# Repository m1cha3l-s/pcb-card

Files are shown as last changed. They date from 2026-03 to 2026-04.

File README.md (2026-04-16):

# m1cha3l's PCB Business card V1
You were luck enough to recieve my pcb business card! You can keep it in your wallet and use the built in ruler or solder the needed components and get a nice desk accessories which has a 6x6 NeoPixel MATRIX, 2 buttons, vibration motor for notifications and a BME280 sensor for presure, humidity and temerature and supports Zigbee, Matter, Thread and bluetooth and wifi.

## Building
You can buy the components I have in my bom to build this together! Also I included headers which you can solder to add more sensors for smart home!

## Firmware
I have included a simple firmware which shows red when the temp from BME280 is over 20℃ and green when under when you press button number 2 and vibrates and shows blue when you press button number 1.
1. Open Arduino IDE
2. Choose seeed xiao ESP32-C6
3. Flash and enjoy!!

## Looks

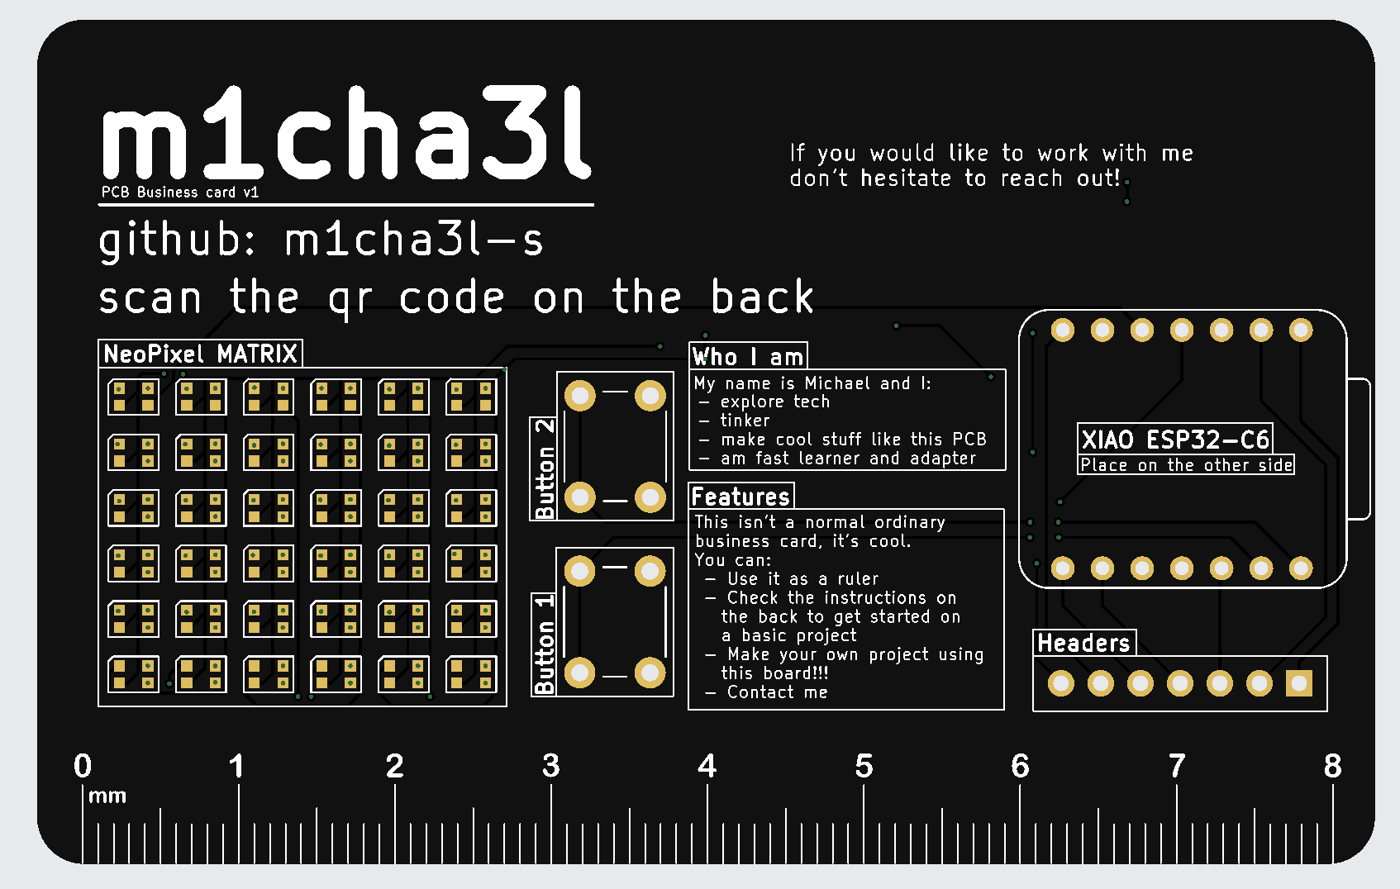
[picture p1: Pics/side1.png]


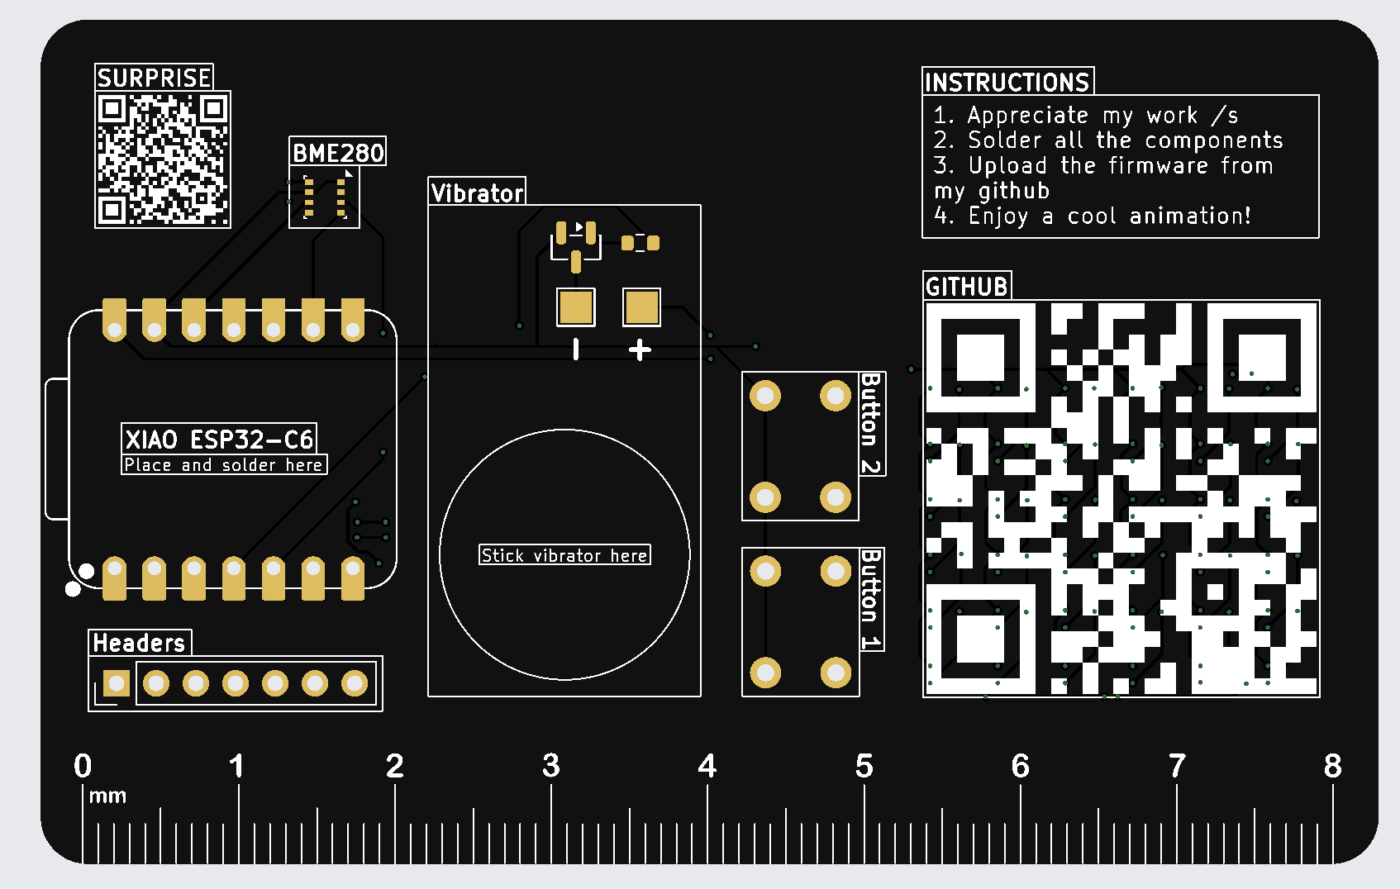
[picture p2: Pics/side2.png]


## Schematic and PCB
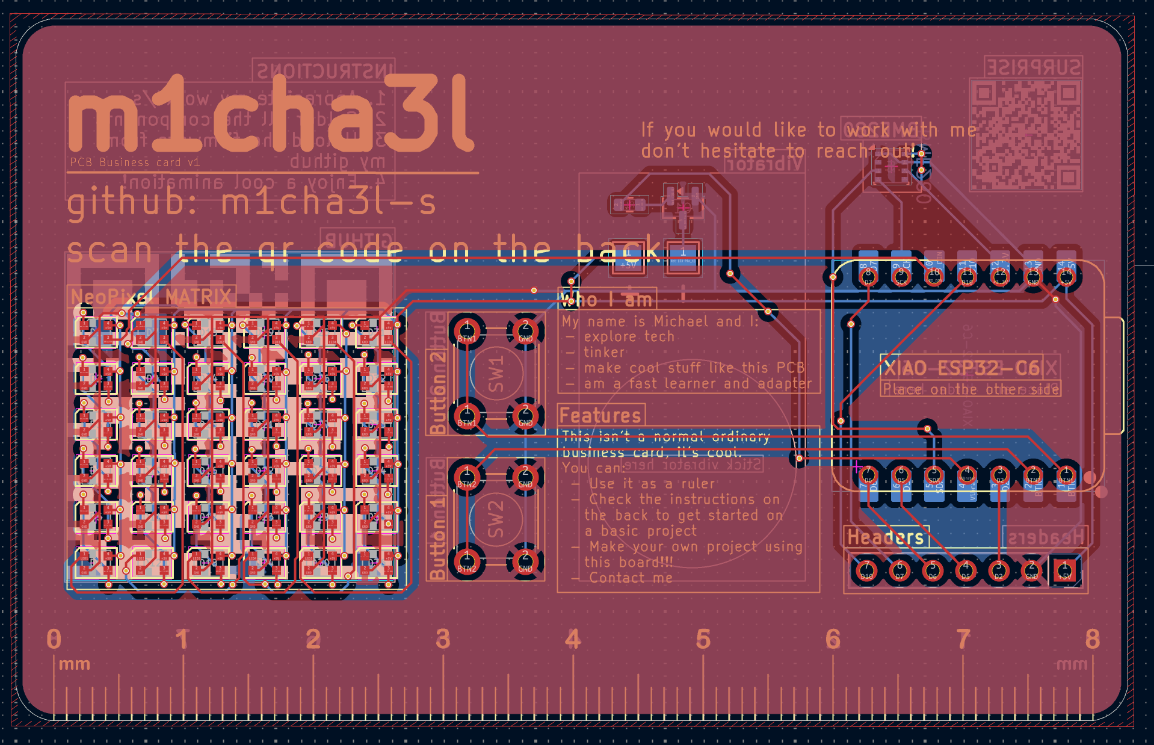
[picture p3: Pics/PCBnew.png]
PCB


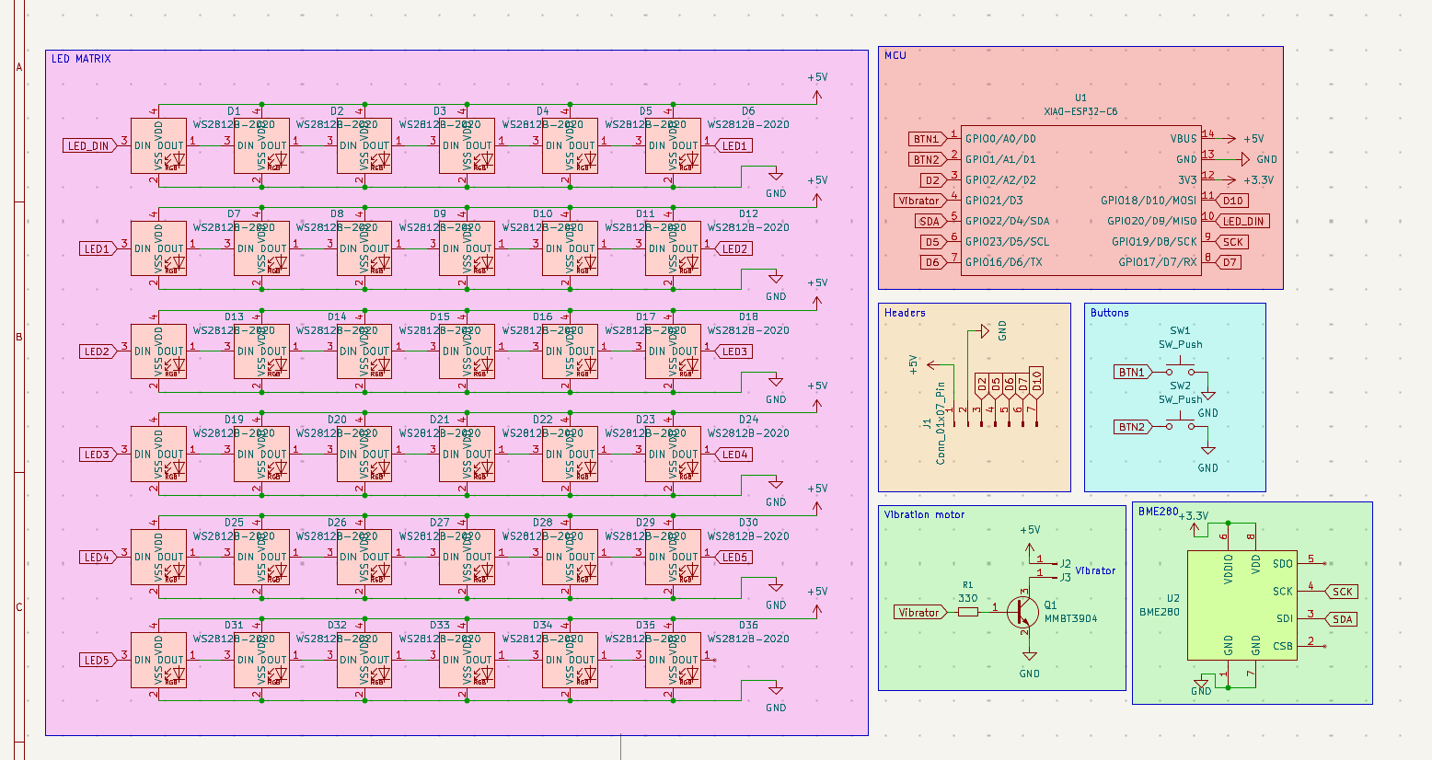
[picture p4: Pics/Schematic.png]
Schematic


## [BOM](https://github.com/m1cha3l-s/pcb-card/blob/main/BOM.csv)

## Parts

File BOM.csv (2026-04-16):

Name | Purpose | Quantity | Total Cost (USD) | Link | Distributor
PCB+Stencil+Shipping+Tax | PCB+Stencil cause idk how to without+Shipping global standart line which is cheapest(I have a 20$ coupon on JLCPCB which I would use to it comes out cheaper | 1 | 4.06 |  | jlcpcb
100PCS SOT-23 MMBT3904 | MMBT3904 | 1 | 0.42 | https://www.aliexpress.com/item/1005009793088130.html | Aliexpress
100PCS/LOTE 0603 SMD Resistor 0R-10M 1/8W 0 1 10 100 150 220 330 ohm 1K 2.2K 10K 100K 0R 1R 10R 100R 150R 220R 330R | SMD resistor | 1 | 0.53 | https://www.aliexpress.com/item/1005002068920572.html | Aliexpress
217℃ Lead-Free High Temp Solder Paste Sn96.5Ag3.0Cu0.5 Needle Tube | Solder paste to do the smd soldering | 1 | 3.21 | https://www.aliexpress.com/item/1005011848494455.html | Aliexpress
G3061 PD65W Mini Hot Plate Digital Soldering Preheating Rework Station PCB SMD Board Soldering Plate Heating Table Repair Tools | Tool to do SMD at home which is cheaper for this board than PCBA | 1 | 17.21 | https://www.aliexpress.com/item/1005006380068665.html | Aliexpress
20PCS Tact Push Button Switch 12V Copper 4Pin SMD Micro Switch 6X6X5 4.3 5 5.5 6 7 8 9 10 11 12 13 15MM TV Toys Home Use Button | Buttonsss (I have them already) | 1 | 0.00 | https://www.aliexpress.com/item/1005005834458965.html | Aliexpress
BME280 LGA-8 MEMS Digital Gas/Pressure/Temperature and Humidity Sensor IC Chip New Original | humidity, pressure and temperature sensor | 1 | 4.38 | https://www.aliexpress.com/item/1005006988103578.html | Aliexpress
50PCS WS2812B-2020 | LEDs for the NeoPixel MATRIX | 1 | 1.27 | https://www.aliexpress.com/item/1005008784230562.html | Aliexpress
DC 3V 3.7V 8mm Round Thin Vibration Motor Button Coin Vibrating Motor Vibrator Phone Massage | Vibration for the board | 1 | 0.41 | https://www.aliexpress.com/item/1005006821274949.html | Aliexpress
XIAO ESP32-C6 | the brain of the thing | 1 | 7.80 | https://botland.cz/moduly-wifi-a-bt-esp32/24783-seeed-xiao-esp32-c6-wifi-bluetooth-seeedstudio-113991254-5904422385705.html | botland

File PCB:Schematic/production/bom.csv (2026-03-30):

Designator | Footprint | Quantity | Value | LCSC Part #
 | f06da421-139f-4461-bd72-0d63481e1e29 | 1
D1, D10, D11, D12, D13, D14, D15, D16, D17, D18, D19, D2, D20, D21, D22, D23, D24, D25, D26, D27, D28, D29, D3, D30, D31, D32, D33, D34, D35, D36, D4, D5, D6, D7, D8, D9 | LED_WS2812B-2020_PLCC4_2.0x2.0mm | 36 | WS2812B-2020
J1 | PinHeader_1x07_P2.54mm_Vertical | 1 | Conn_01x07_Pin
J2, J3 | TestPoint_Pad_2.0x2.0mm | 2 | Conn_01x01_Pin
Q1 | SOT-23 | 1 | MMBT3904
R1 | 0603 | 1 | 330
SW1, SW2 | SW_PUSH_6mm_H4.3mm | 2 | SW_Push
U1 | XIAO-ESP32C6-DIP | 1 | XIAO-ESP32-C6
U2 | Bosch_LGA-8_2.5x2.5mm_P0.65mm_ClockwisePinNumbering | 1 | BME280

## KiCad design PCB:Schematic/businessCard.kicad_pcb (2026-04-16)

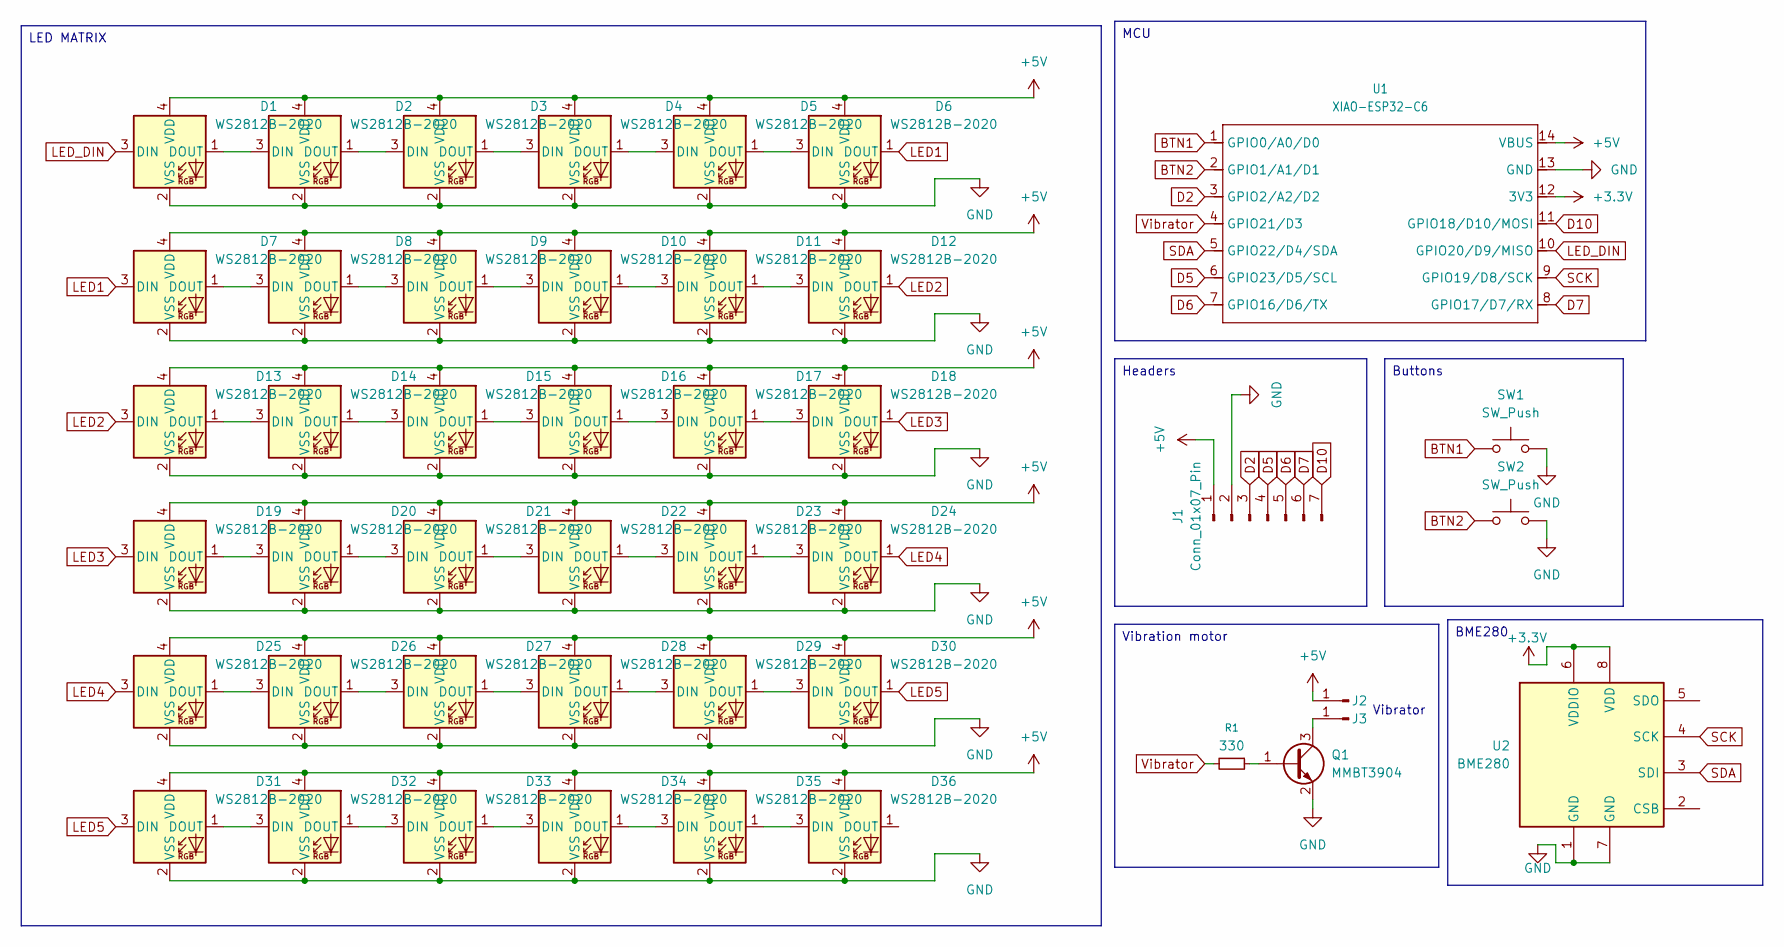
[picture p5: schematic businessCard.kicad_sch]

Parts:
D1, D2, D3, D4, D5, D6, D7, D8, D9, D10, D11, D12, D13, D14, D15, D16, D17, D18, D19, D20, D21, D22, D23, D24, D25, D26, D27, D28, D29, D30, D31, D32, D33, D34, D35, D36: WS2812B-2020; LED_WS2812B-2020_PLCC4_2.0x2.0mm
J1: Conn_01x07_Pin; PinHeader_1x07_P2.54mm_Vertical
J2, J3: Conn_01x01_Pin; TestPoint_Pad_2.0x2.0mm
Q1: MMBT3904; SOT-23
R1: 330; R_0603_1608Metric
SW1, SW2: SW_Push; SW_PUSH_6mm_H4.3mm
U1: XIAO-ESP32-C6; XIAO-ESP32C6-DIP
U2: BME280; Bosch_LGA-8_2.5x2.5mm_P0.65mm_ClockwisePinNumbering

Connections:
+3.3V: U1.12 (3V3), U2.6 (VDDIO), U2.8 (VDD)
+5V: D1.4 (VDD), D2.4 (VDD), D3.4 (VDD), D4.4 (VDD), D5.4 (VDD), D6.4 (VDD), D7.4 (VDD), D8.4 (VDD), D9.4 (VDD), D10.4 (VDD), D11.4 (VDD), D12.4 (VDD), D13.4 (VDD), D14.4 (VDD), D15.4 (VDD), D16.4 (VDD), D17.4 (VDD), D18.4 (VDD), D19.4 (VDD), D20.4 (VDD), D21.4 (VDD), D22.4 (VDD), D23.4 (VDD), D24.4 (VDD), D25.4 (VDD), D26.4 (VDD), D27.4 (VDD), D28.4 (VDD), D29.4 (VDD), D30.4 (VDD), D31.4 (VDD), D32.4 (VDD), D33.4 (VDD), D34.4 (VDD), D35.4 (VDD), D36.4 (VDD), J1.1, J2.1, U1.14 (VBUS)
BTN1: SW1.1, U1.1 (GPIO0/A0/D0)
BTN2: SW2.1, U1.2 (GPIO1/A1/D1)
D2: J1.3, U1.3 (GPIO2/A2/D2)
D5: J1.4, U1.6 (GPIO23/D5/SCL)
D6: J1.5, U1.7 (GPIO16/D6/TX)
D7: J1.6, U1.8 (GPIO17/D7/RX)
D10: J1.7, U1.11 (GPIO18/D10/MOSI)
GND: D1.2 (VSS), D2.2 (VSS), D3.2 (VSS), D4.2 (VSS), D5.2 (VSS), D6.2 (VSS), D7.2 (VSS), D8.2 (VSS), D9.2 (VSS), D10.2 (VSS), D11.2 (VSS), D12.2 (VSS), D13.2 (VSS), D14.2 (VSS), D15.2 (VSS), D16.2 (VSS), D17.2 (VSS), D18.2 (VSS), D19.2 (VSS), D20.2 (VSS), D21.2 (VSS), D22.2 (VSS), D23.2 (VSS), D24.2 (VSS), D25.2 (VSS), D26.2 (VSS), D27.2 (VSS), D28.2 (VSS), D29.2 (VSS), D30.2 (VSS), D31.2 (VSS), D32.2 (VSS), D33.2 (VSS), D34.2 (VSS), D35.2 (VSS), D36.2 (VSS), J1.2, Q1.2 (E), SW1.2, SW2.2, U1.13 (GND), U2.1 (GND), U2.7 (GND)
LED1: D6.1 (DOUT), D7.3 (DIN)
LED2: D12.1 (DOUT), D13.3 (DIN)
LED3: D18.1 (DOUT), D19.3 (DIN)
LED4: D24.1 (DOUT), D25.3 (DIN)
LED5: D30.1 (DOUT), D31.3 (DIN)
LED_DIN: D1.3 (DIN), U1.10 (GPIO20/D9/MISO)
unnamed: D1.1 (DOUT), D2.3 (DIN)
unnamed: D2.1 (DOUT), D3.3 (DIN)
unnamed: D3.1 (DOUT), D4.3 (DIN)
unnamed: D4.1 (DOUT), D5.3 (DIN)
unnamed: D5.1 (DOUT), D6.3 (DIN)
unnamed: D7.1 (DOUT), D8.3 (DIN)
unnamed: D8.1 (DOUT), D9.3 (DIN)
unnamed: D9.1 (DOUT), D10.3 (DIN)
unnamed: D10.1 (DOUT), D11.3 (DIN)
unnamed: D11.1 (DOUT), D12.3 (DIN)
unnamed: D13.1 (DOUT), D14.3 (DIN)
unnamed: D14.1 (DOUT), D15.3 (DIN)
unnamed: D15.1 (DOUT), D16.3 (DIN)
unnamed: D16.1 (DOUT), D17.3 (DIN)
unnamed: D17.1 (DOUT), D18.3 (DIN)
unnamed: D19.1 (DOUT), D20.3 (DIN)
unnamed: D20.1 (DOUT), D21.3 (DIN)
unnamed: D21.1 (DOUT), D22.3 (DIN)
unnamed: D22.1 (DOUT), D23.3 (DIN)
unnamed: D23.1 (DOUT), D24.3 (DIN)
unnamed: D25.1 (DOUT), D26.3 (DIN)
unnamed: D26.1 (DOUT), D27.3 (DIN)
unnamed: D27.1 (DOUT), D28.3 (DIN)
unnamed: D28.1 (DOUT), D29.3 (DIN)
unnamed: D29.1 (DOUT), D30.3 (DIN)
unnamed: D31.1 (DOUT), D32.3 (DIN)
unnamed: D32.1 (DOUT), D33.3 (DIN)
unnamed: D33.1 (DOUT), D34.3 (DIN)
unnamed: D34.1 (DOUT), D35.3 (DIN)
unnamed: D35.1 (DOUT), D36.3 (DIN)
unnamed: J3.1, Q1.3 (C)
unnamed: Q1.1 (B), R1.1
SCK: U1.9 (GPIO19/D8/SCK), U2.4 (SCK)
SDA: U1.5 (GPIO22/D4/SDA), U2.3 (SDI)
Vibrator: R1.2, U1.4 (GPIO21/D3)

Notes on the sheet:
Vibrator
Headers
LED MATRIX
MCU
BME280
Buttons
Vibration motor

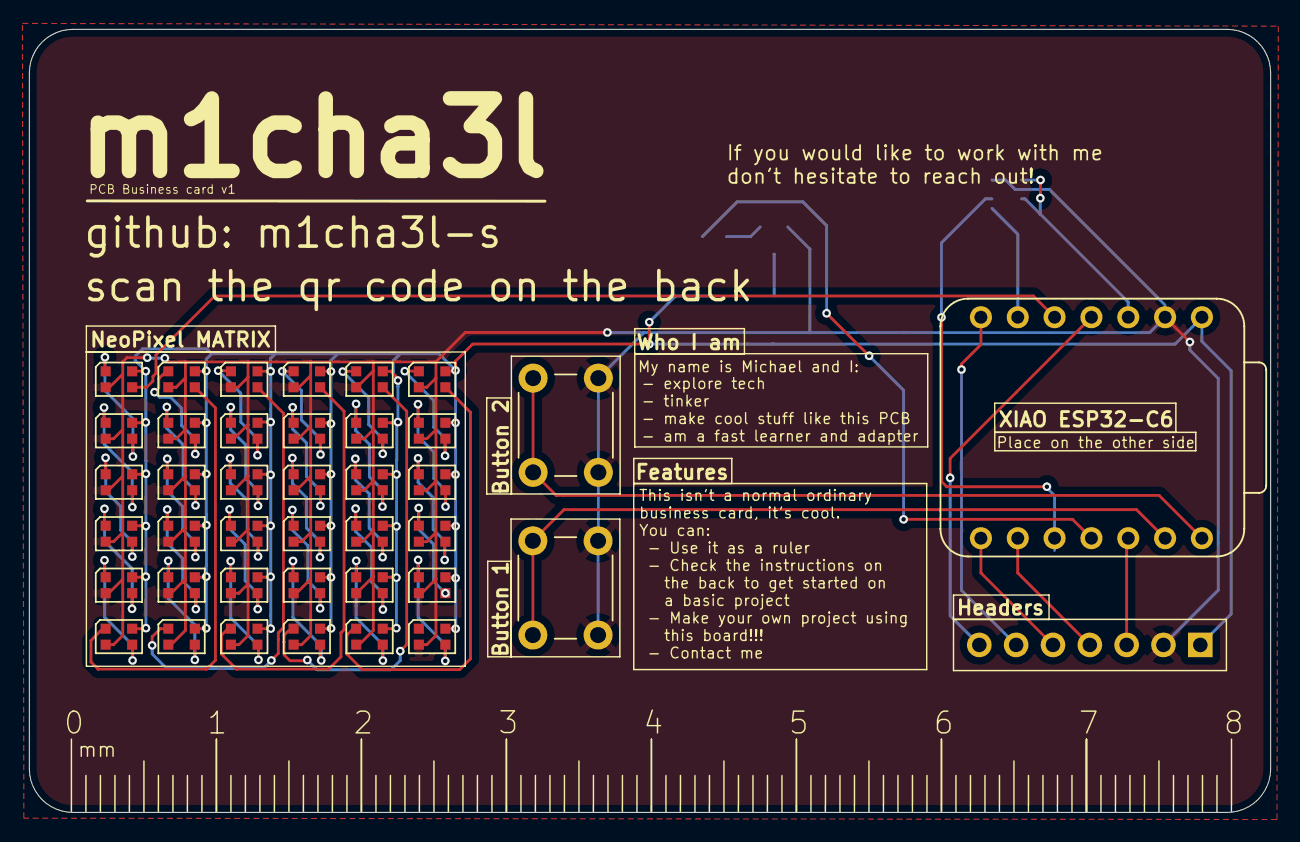
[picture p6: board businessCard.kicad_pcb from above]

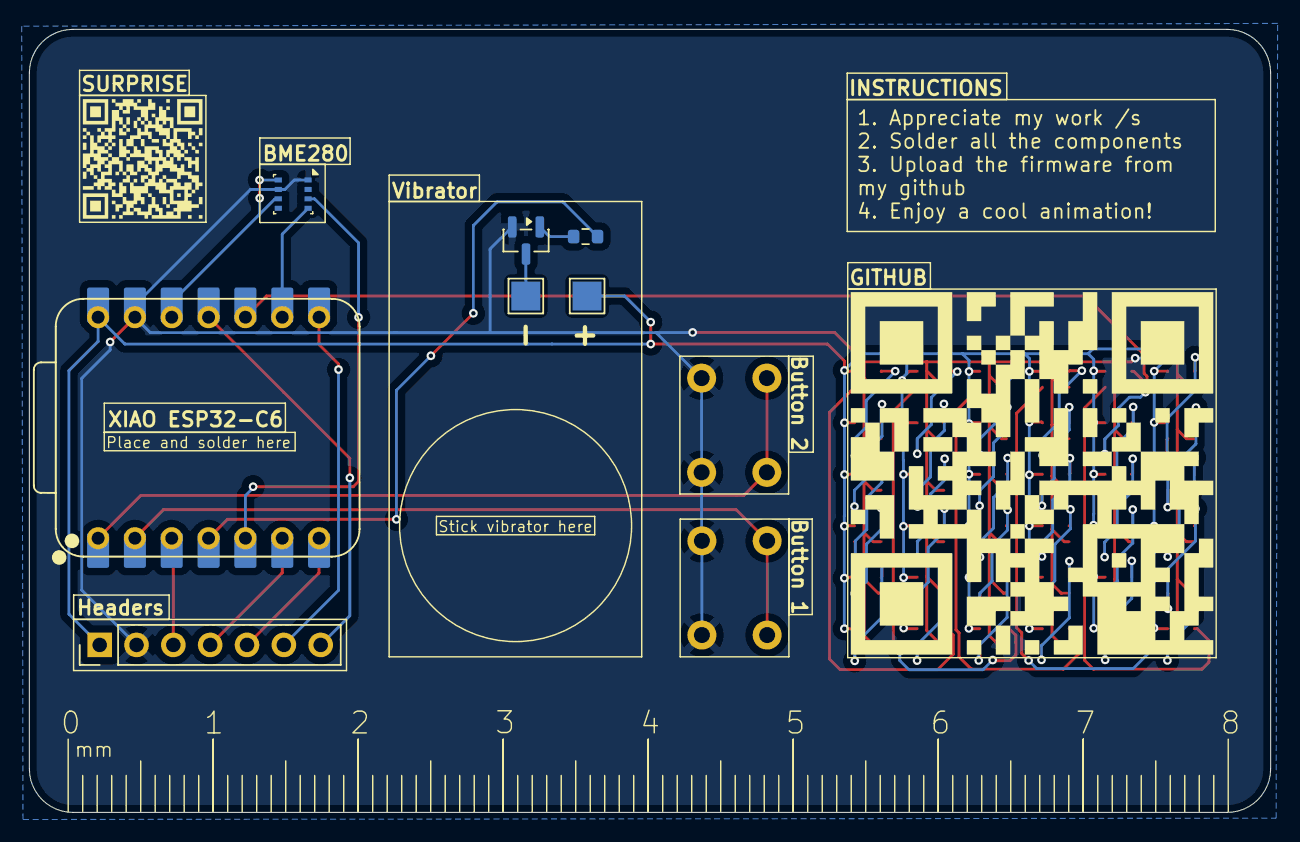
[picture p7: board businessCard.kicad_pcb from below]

Board: 2 copper layers, 85.6 x 54.0 mm, 47 parts (9 on the bottom side), 51 nets.

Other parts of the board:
QR*****: https://www.youtube.com/watch?v=dQw4w9WgXcQ; //www.youtube.com/watch?v=dQw4w9WgXcQ
QR*****#2: big-githubqr

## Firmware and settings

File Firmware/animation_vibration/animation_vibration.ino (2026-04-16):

#include <Adafruit_GFX.h>
#include <Adafruit_NeoMatrix.h>
#include <Adafruit_NeoPixel.h>
#include <Wire.h>
#include <Adafruit_BME280.h>
#include <Adafruit_Sensor.h>

Adafruit_BME280 bme;

Adafruit_NeoMatrix matrix = Adafruit_NeoMatrix(6, 6, D9,   
  NEO_MATRIX_TOP     + NEO_MATRIX_LEFT +
  NEO_MATRIX_ROWS + NEO_MATRIX_PROGRESSIVE,
  NEO_GRB            + NEO_KHZ800);

int button1 = LOW;
int button2 = LOW;

void setup() {
  Serial.begin(115200);
  pinMode(0, INPUT);
  pinMode(1, INPUT);
  pinMode(3, OUTPUT);

  bme.begin(0x76);
  float temp = bme.readTemperature();

  matrix.begin();
  matrix.setBrightness(0);
  matrix.show();
}

void loop() {
  button1 = digitalRead(0);
  button2 = digitalRead(1);
  float temp = bme.readTemperature();
  if (button1 == HIGH) {
    digitalWrite(3, HIGH);
    matrix.fillScreen(matrix.Color(0, 0, 255));
    matrix.setBrightness(255);
    matrix.show();
    delay(500);
    matrix.setBrightness(0);
    matrix.show();
    digitalWrite(3, LOW);
    Serial.println("Button 1 was activated and I vibrated!");

  }
  else if (button2 == HIGH) {
    if (temp <= 20) {
        matrix.fillScreen(matrix.Color(0, 255, 0));
        matrix.setBrightness(255);
        matrix.show();
        delay(1500);
        matrix.setBrightness(0);
        matrix.show();
        Serial.println("Button 2 was activated and the temp was under 20 C");
    } else {
        matrix.fillScreen(matrix.Color(255, 0, 0));
        matrix.setBrightness(255);
        matrix.show();
        delay(1500);
        matrix.setBrightness(0);
        matrix.show();
        Serial.println("Button 2 was activated and the temp was over 20 C");

    } 
  }
  Serial.println(temp);
}

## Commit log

2026-03-30 Added pcb source and gerbers + BOM
    [BOM.csv, bom.csv, businessCard.kicad_pcb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]
2026-04-16 changed button2 to fill matrix based on temp
2026-04-16 button1 now shows blue on the matrix
2026-04-16 added updated pcb stuff
    [businessCard.kicad_pcb]
2026-04-16 new pcb pic
2026-04-16 Added serial print functions
